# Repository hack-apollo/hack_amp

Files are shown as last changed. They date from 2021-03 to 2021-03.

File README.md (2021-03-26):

HACK LABS POWER AMP (TPA3116D2) : https://www.youtube.com/watch?v=O-adCBWkxsg&t=2s                                                                             
Author: HACK实验室                                                                                     
YouTube ID: HACK实验室, welcome to subscribe https://www.youtube.com/c/HACK实验室                                                       
HACK_PowerAmp is a free download and may be used, modified, evaluated and
distributed without charge provided the user adheres to version three of the GNU
General Public License (GPL) and does not remove the copyright notice or this
text.  The GPL V3 text is available on the gnu.org web site
作者：HACK实验室                                                                                        
B站ID：HACK实验室  欢迎订阅 https://space.bilibili.com/395145107                                                                            
微信公众号：HACK实验室，开源资料唯一发布点，定期分享开源硬件以及有价值的技术文章，欢迎关注.   

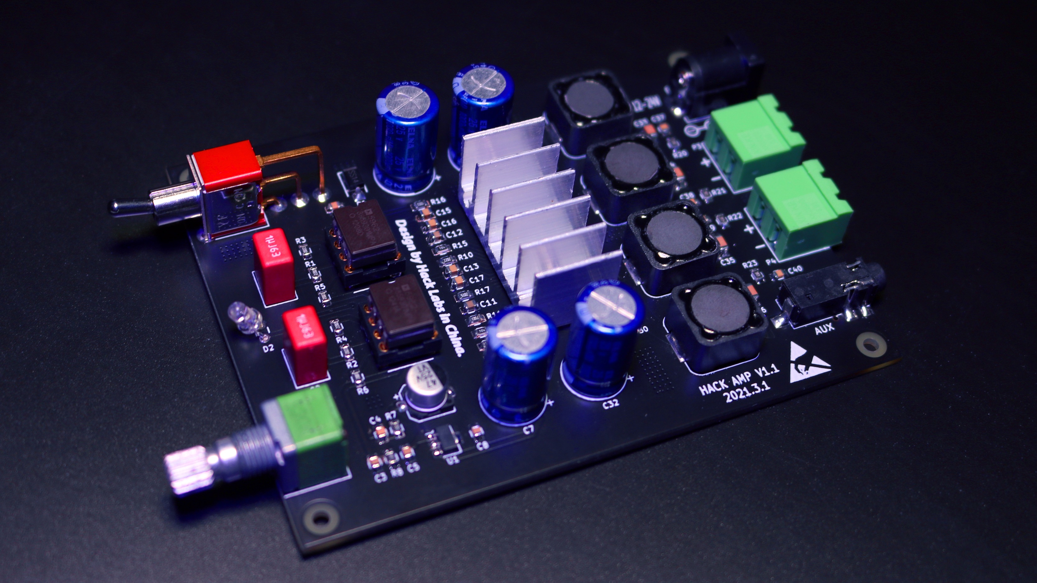
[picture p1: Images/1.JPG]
Image text


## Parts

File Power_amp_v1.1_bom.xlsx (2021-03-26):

编号 | 名称 | 值 | 封装 | 数量 | 备注
C1,C2 | WIMA MKS 02 | 1uF ±5% 63V | 脚距5mm | 2
C3,C4,C5,C8,C9,C29,C30,C51,C52 | X7R | 0.1uF ±10% 50V | 0805_C | 9
C6,C7,C31,C32 | 伊娜电容 | 220uF 35V（或1000uF/25V） | 10*16mm | 4 | 需注意电源电压要小于耐压值，且需留有余量
C10 | 贴片铝电解电容 | 47UF 25V | 6.3*5.4mm | 1
C11,C12,C13,C15,C16,C17 | X7R | 1uF ±10% 25V | 0805_C | 6
C27,C28 | X7R | 1nF(1000pF) ±5% 50V | 0805_C | 2
C19,C20,C21,C22 | X5R | 220nF ±10% 35V | 0805_C | 4
C33,C34,C35,C36 | X7R | 680nF ±10% 50V | 1206_C | 4
C37,C38,C39,C40 | X7R | 10nF ±10% 100V | 0805_C | 4
R1,R2,R5,R6,R9 |  | 10KΩ | 0805_R | 5
R3,R4,R10 |  | 20KΩ | 0805_R | 3
R7,R8,R12,R13,R14,R15,R16 |  | 100KΩ | 0805_R | 7
R11 |  | 750KΩ | 0805_R | 1
R17 |  | 51KΩ | 0805_R | 1 | 大小决定开机延时时间
R20,R21,R22,R23 |  | 3.3Ω | 0805_R | 4
D1 | 肖特基二极管 | SS34 | SMA | 1
D2 | 直插LED灯 |  | 脚距2.54mm | 1
L1,L2,L3,L4 | 贴片电感 | CDRH127 10uH/5.4A | 12*12*7mm | 4
U1 | CJ78L12 | 0.1A/12V | SOT-89-3 | 1
U2,U3 | NE5532P |  | DIP-8 | 2
U4 | TPA3116D2 |  | TSSOP-32 | 1
SW1 | 钮子开关 | MTS-102C4 |  | 1
RV1 | 09型双联电位器 | B20K |  | 1
CON1 | 电源母座 | DC-005-2.5内芯 |  | 1
P2 | 3.5音频母座 | PJ-328 | 贴片 | 1
P3,P4 | 接线端子 | 2EDG5.08-2P |  | 2
如果整理有误还望见谅，可到“HACK实验室”微信公众号私信通知修改，谢谢！

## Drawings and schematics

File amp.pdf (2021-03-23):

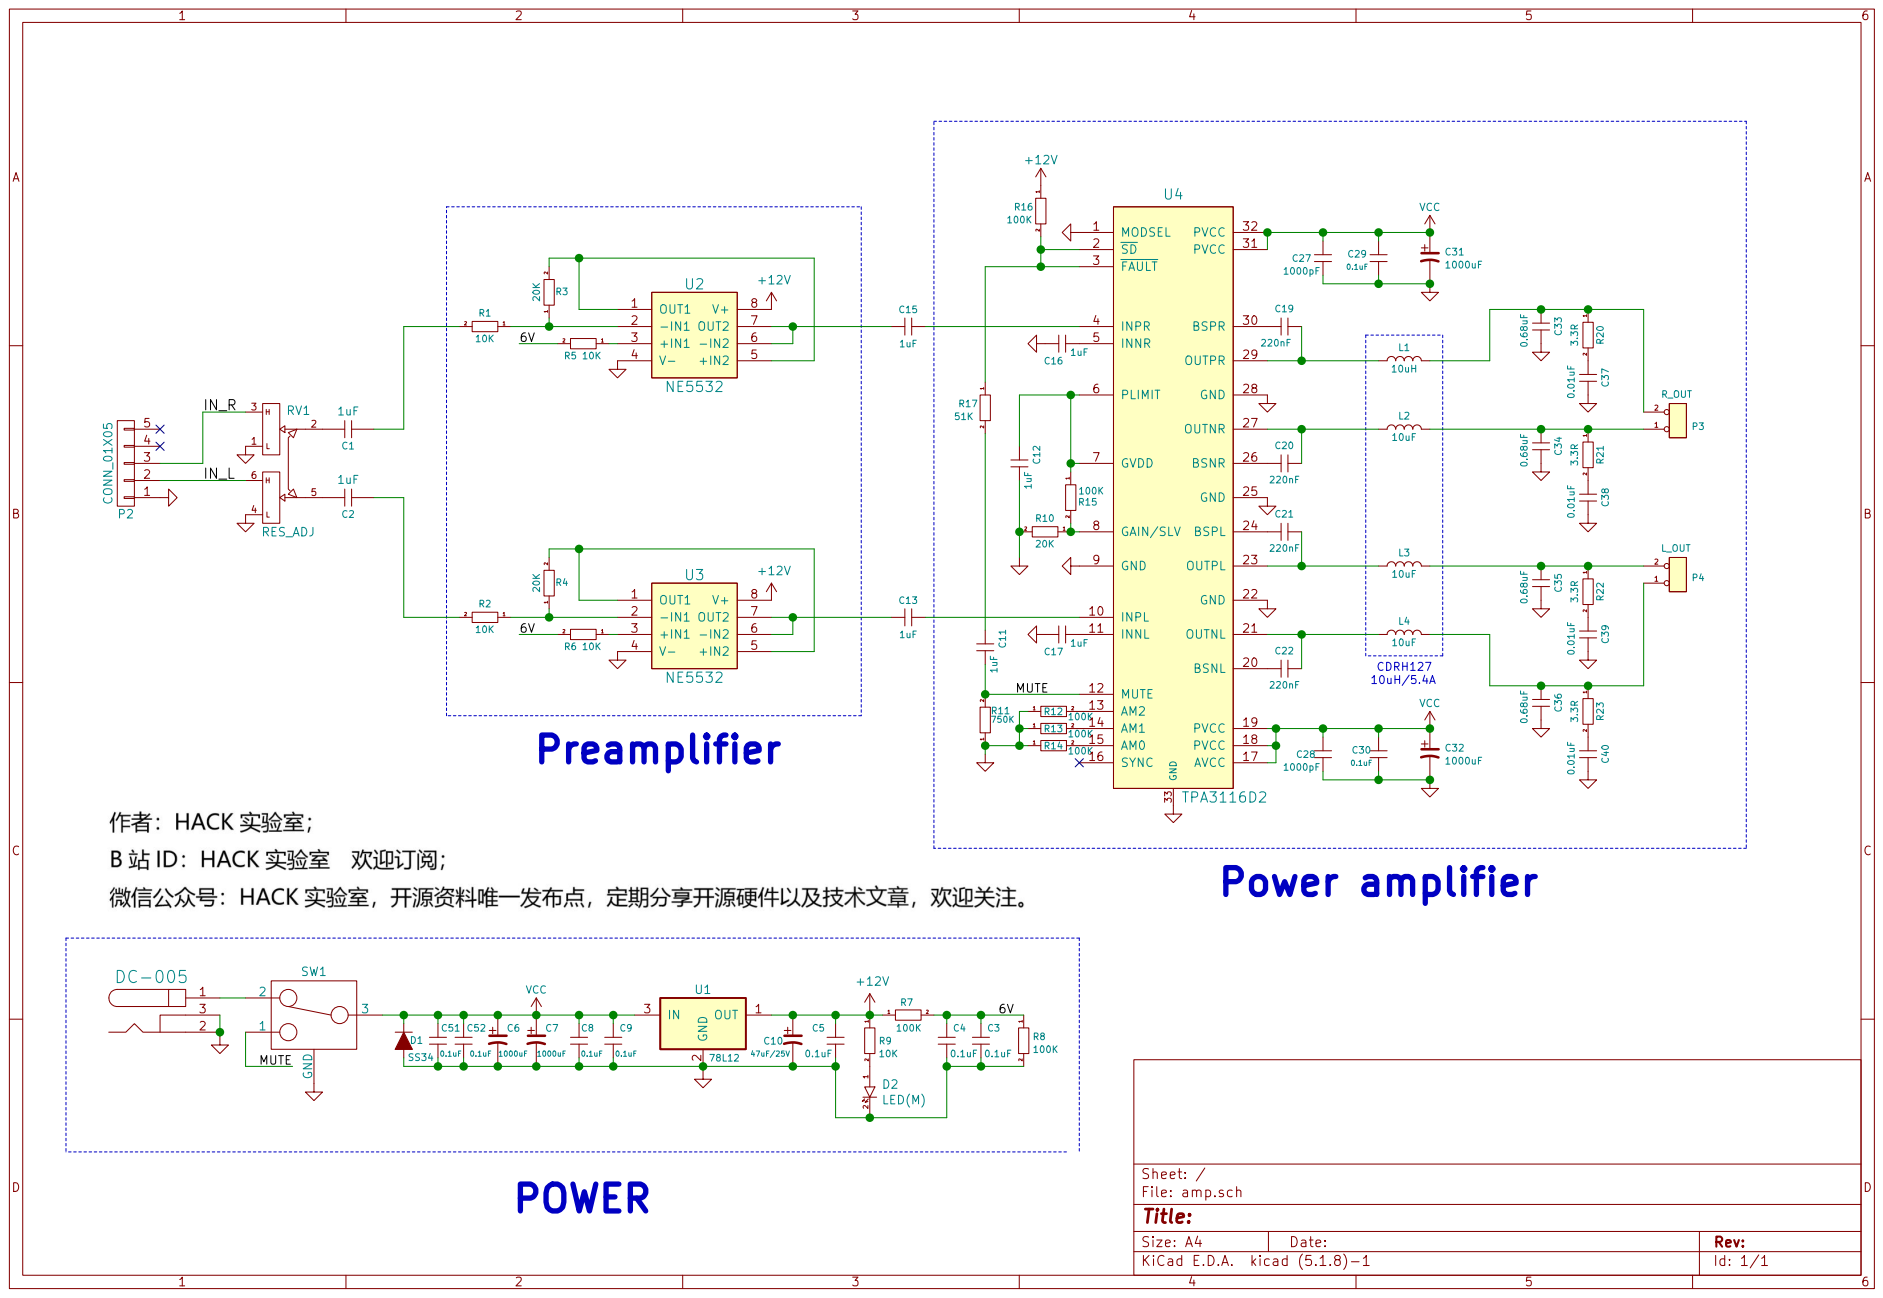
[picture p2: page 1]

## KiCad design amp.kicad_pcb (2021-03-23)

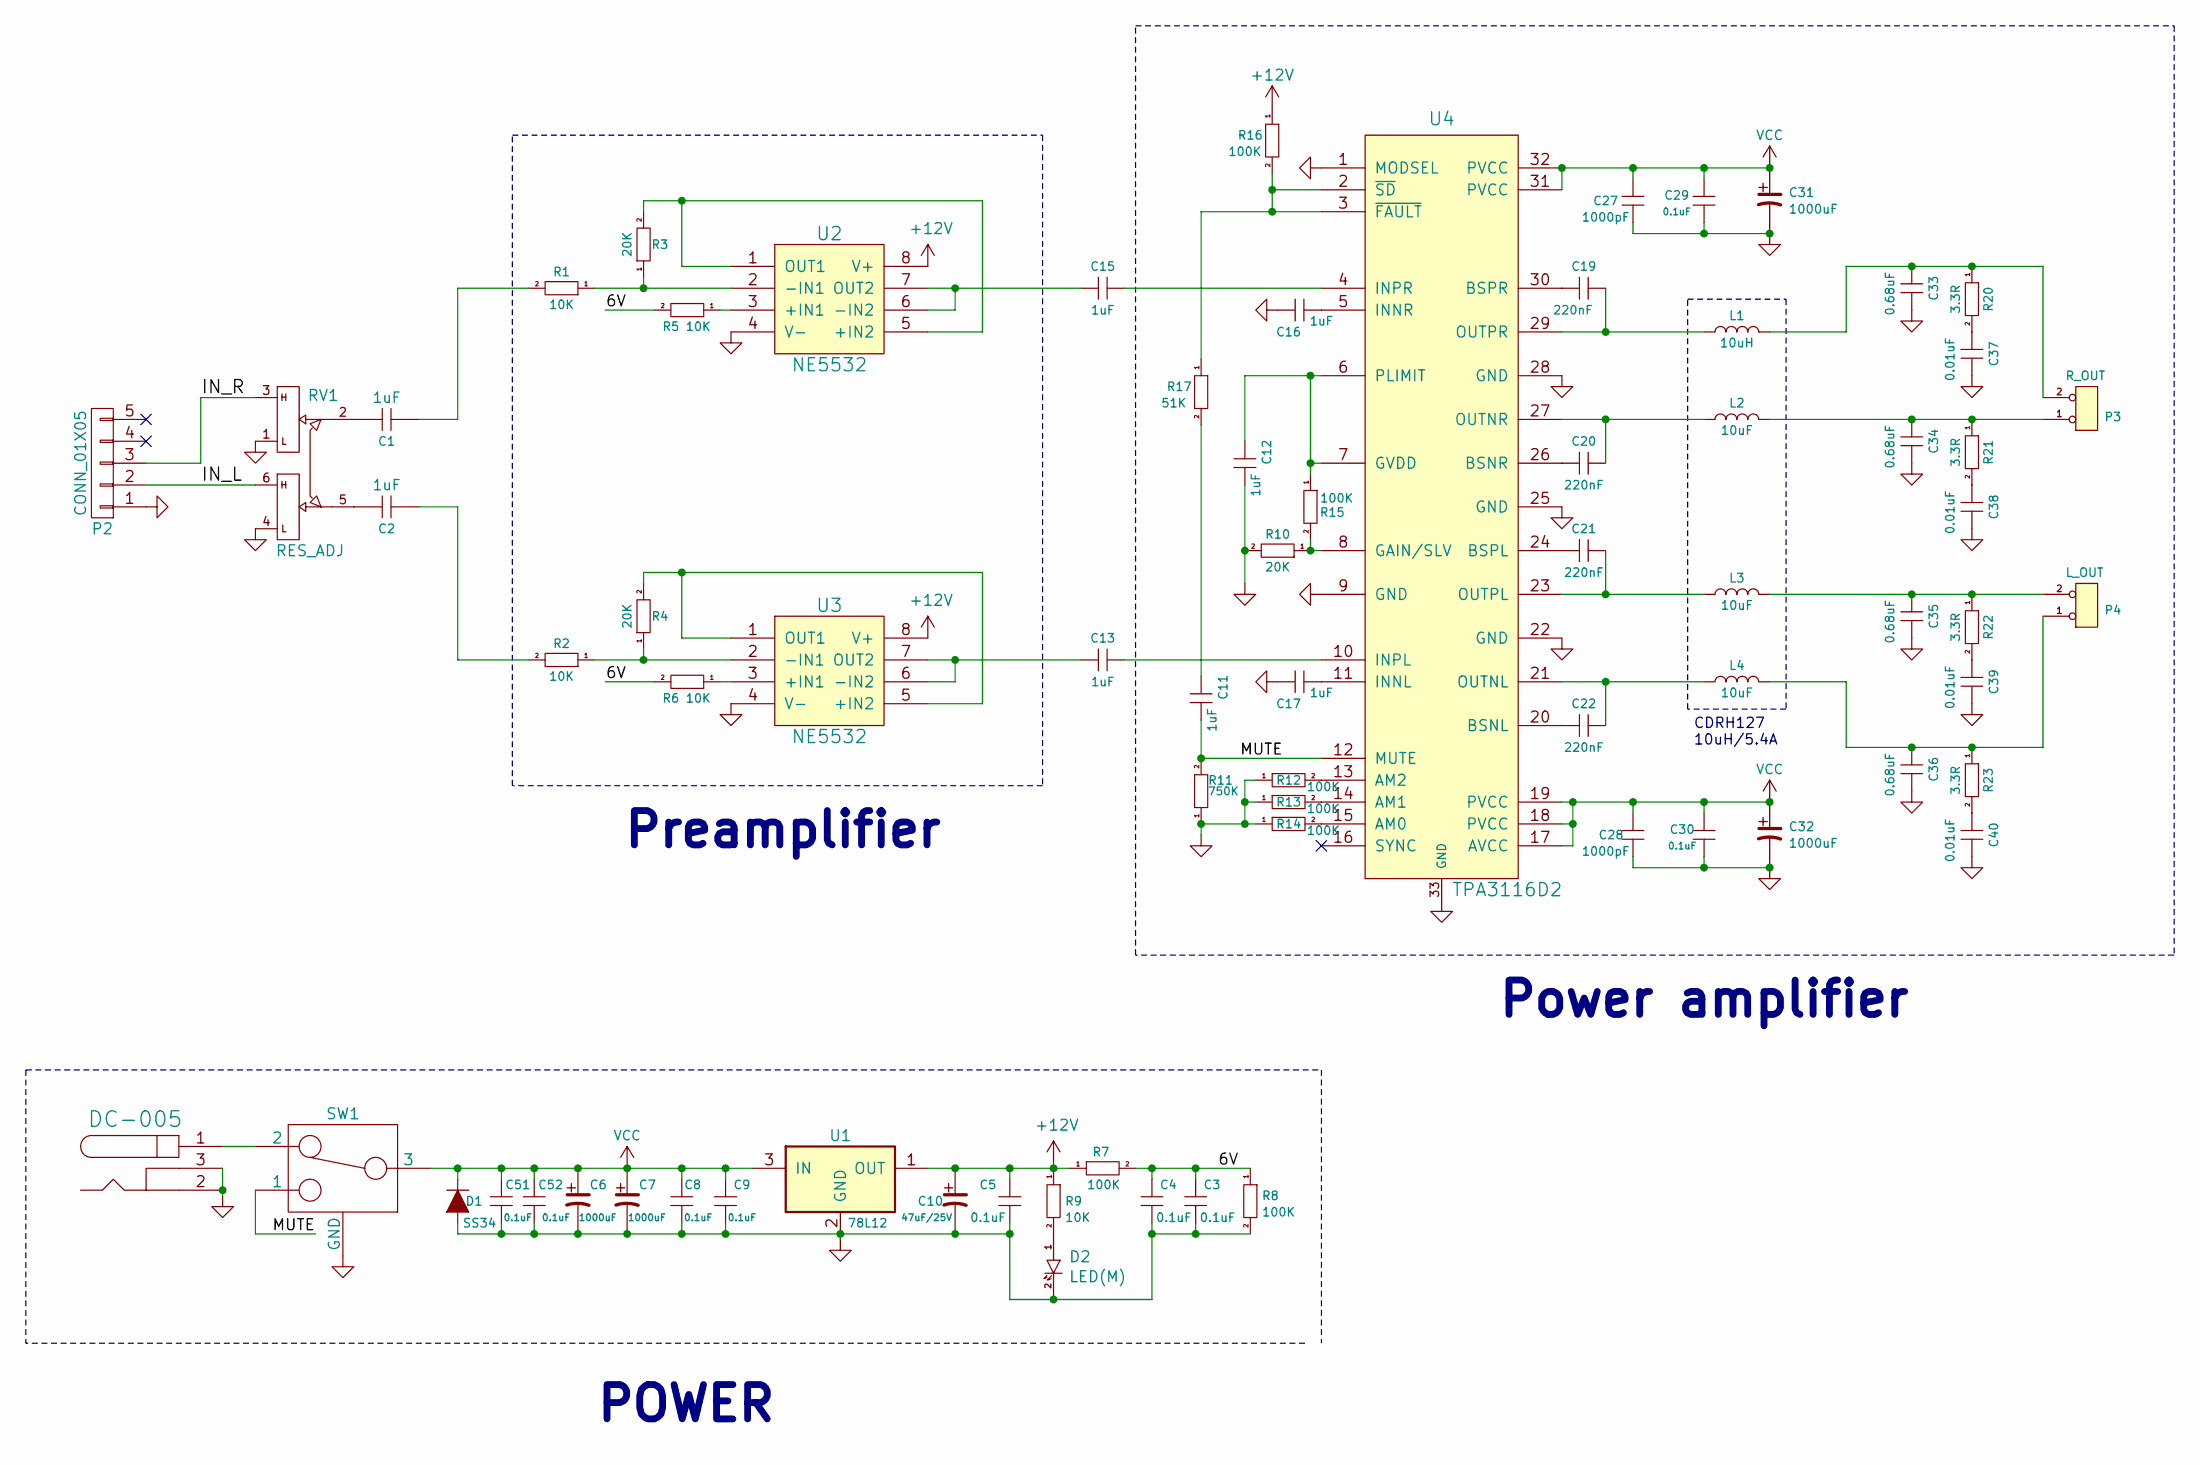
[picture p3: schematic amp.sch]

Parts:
C1, C2: 1uF; CP_Radial_D5.0mm_P2.50mm
C3, C4, C5, C8, C9, C29, C30, C51, C52: 0.1uF; 0805_C
C6, C7, C31, C32: 1000uF; CP_Radial_D10.0mm_P5.00mm
C10: 47uF/25V; CP_Radial_D10.0mm_P5.00mm
C11, C12, C13, C15, C16, C17: 1uF; 0805_C
C19, C20, C21, C22: 220nF; 0805_C
C27, C28: 1000pF; 0805_C
C33, C34, C35, C36: 0.68uF; 0805_C
C37, C38, C39, C40: 0.01uF; 0805_C
CON1: DC-005; DCDCJACK_ALIM
D1: SS34; D_SMA
D2: LED(M); LED-3MM
L1: 10uH; L_Bourns_SRR1260
L2, L3, L4: 10uF; L_Bourns_SRR1260
P2: CONN_01X05; Audio_3.5mm
P3: R_OUT; PhoenixContact_MSTBA_2,5_2-G_1x02_P5.00mm_Horizontal
P4: L_OUT; PhoenixContact_MSTBA_2,5_2-G_1x02_P5.00mm_Horizontal
R1, R2, R5, R6, R9: 10K; 0805_R
R3, R4, R10: 20K; 0805_R
R7, R8, R12, R13, R14, R15, R16: 100K; 0805_R
R11: 750K; 0805_R
R17: 51K; 0805_R
R20, R21, R22, R23: 3.3R; 0805_R
RV1: RES_ADJ; ADJ_RES
SW1: SWITCH_INV; SWITCH_Toggle
U1: 78L12; SOT-89-3
U2, U3: NE5532; DIP-8_NEW
U4: TPA3116D2; HTSSOP-32-1EP

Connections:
+9V: C5.1, C10.1, R7.1, R9.1, R16.1, U1.1 (OUT), U2.8 (V+), U3.8 (V+)
/4.5V: C3.1, C4.1, R5.2, R6.2, R7.2, R8.1
/IN_L: P2.2, RV1.6
/IN_R: P2.3, RV1.3
/MUTE: C11.2, R11.2, SW1.1, U4.12 (MUTE)
GND: C3.2, C4.2, C5.2, C6.2, C7.2, C8.2, C9.2, C10.2, C12.2, C16.1, C17.1, C27.2, C28.2, C29.2, C30.2, C31.2, C32.2, C33.1, C34.1, C35.1, C36.1, C37.1, C38.1, C39.1, C40.1, C51.2, C52.2, CON1.2, CON1.3, D1.1 (A), D2.2 (K), P2.1, R8.2, R10.2, R11.1, R12.1, R13.1, R14.1, RV1.1, RV1.4, SW1.0 (GND), U1.2 (GND), U2.4 (V-), U3.4 (V-), U4.1 (MODSEL), U4.9 (GND), U4.22 (GND), U4.25 (GND), U4.28 (GND), U4.33 (GND)
unnamed: C1.1, RV1.2
unnamed: C1.2, R1.2
unnamed: C2.1, RV1.5
unnamed: C2.2, R2.2
unnamed: C11.1, R17.2
unnamed: C12.1, R15.1, U4.6 (PLIMIT), U4.7 (GVDD)
unnamed: C13.1, U3.6 (-IN2), U3.7 (OUT2)
unnamed: C13.2, U4.10 (INPL)
unnamed: C15.1, U2.6 (-IN2), U2.7 (OUT2)
unnamed: C15.2, U4.4 (INPR)
unnamed: C16.2, U4.5 (INNR)
unnamed: C17.2, U4.11 (INNL)
unnamed: C19.1, L1.1, U4.29 (OUTPR)
unnamed: C19.2, U4.30 (BSPR)
unnamed: C20.1, L2.1, U4.27 (OUTNR)
unnamed: C20.2, U4.26 (BSNR)
unnamed: C21.1, L3.1, U4.23 (OUTPL)
unnamed: C21.2, U4.24 (BSPL)
unnamed: C22.1, L4.1, U4.21 (OUTNL)
unnamed: C22.2, U4.20 (BSNL)
unnamed: C33.2, L1.2, P3.2 (PM), R20.1
unnamed: C34.2, L2.2, P3.1, R21.1
unnamed: C35.2, L3.2, P4.2 (PM), R22.1
unnamed: C36.2, L4.2, P4.1, R23.1
unnamed: C37.2, R20.2
unnamed: C38.2, R21.2
unnamed: C39.2, R22.2
unnamed: C40.2, R23.2
unnamed: CON1.1, SW1.2
unnamed: D2.1 (A), R9.2
unnamed: R1.1, R3.1, U2.2 (-IN1)
unnamed: R2.1, R4.1, U3.2 (-IN1)
unnamed: R3.2, U2.1 (OUT1), U2.5 (+IN2)
unnamed: R4.2, U3.1 (OUT1), U3.5 (+IN2)
unnamed: R5.1, U2.3 (+IN1)
unnamed: R6.1, U3.3 (+IN1)
unnamed: R10.1, R15.2, U4.8 (GAIN/SLV)
unnamed: R12.2, U4.13 (AM2)
unnamed: R13.2, U4.14 (AM1)
unnamed: R14.2, U4.15 (AM0)
unnamed: R16.2, R17.1, U4.2 (~SD), U4.3 (~FAULT)
VCC: C6.1, C7.1, C8.1, C9.1, C27.1, C28.1, C29.1, C30.1, C31.1, C32.1, C51.1, C52.1, D1.2 (K), SW1.3, U1.3 (IN), U4.17 (AVCC), U4.18 (PVCC), U4.19 (PVCC), U4.31 (PVCC), U4.32 (PVCC)

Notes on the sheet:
CDRH127 10uH/5.4A
POWER
Preamplifier
Power amplifier

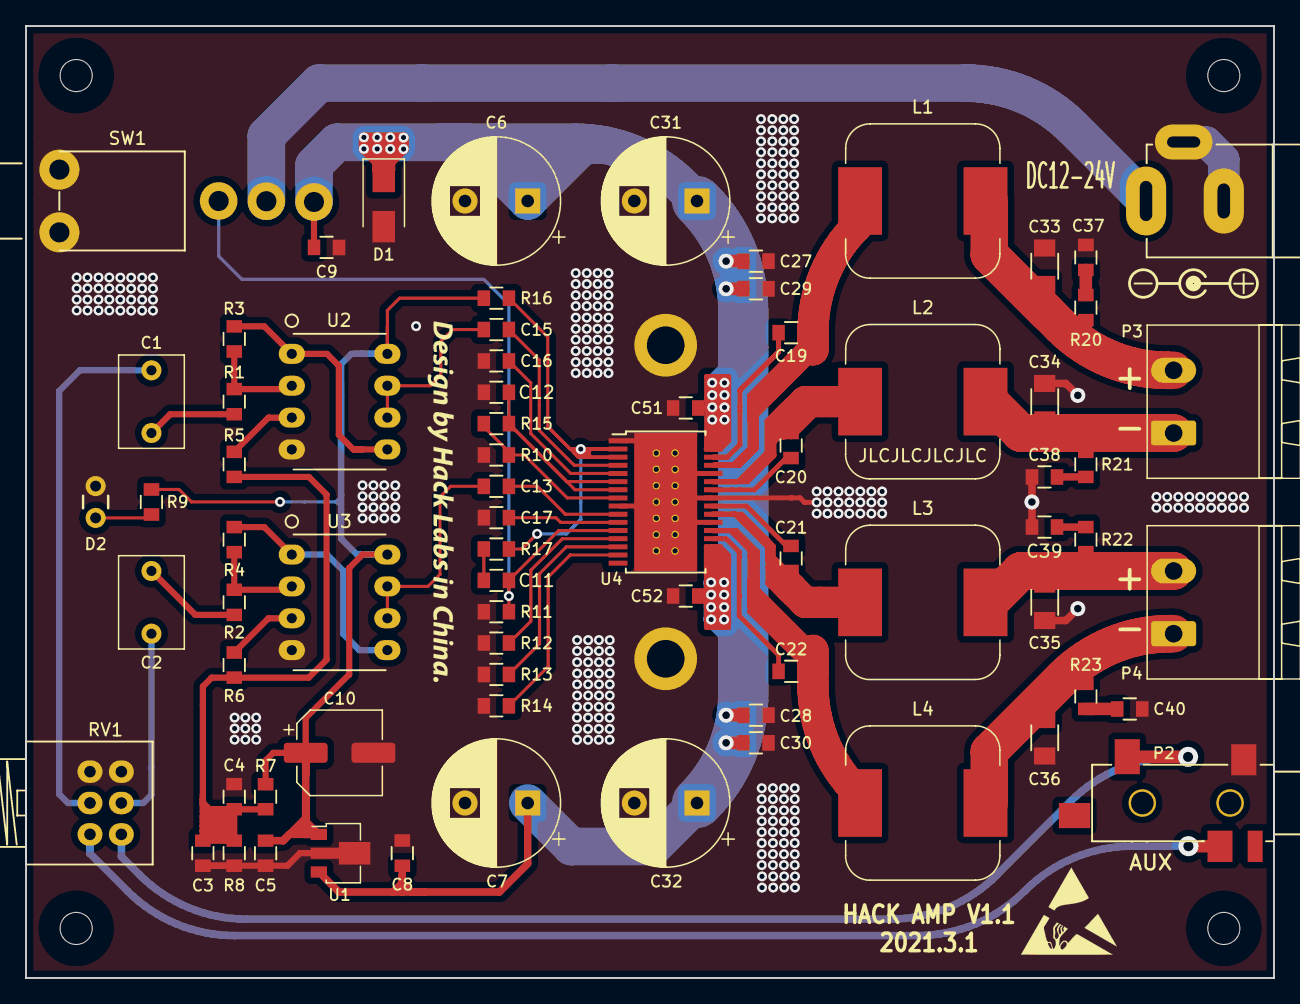
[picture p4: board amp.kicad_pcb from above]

Board: 2 copper layers, 99.5 x 75.9 mm, 73 parts (0 on the bottom side), 48 nets.

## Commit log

2021-03-23 first add
    [HiFi功放V1.1元器件清单.xlsx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]
2021-03-23 repare bom
    [Power_amp_v1.1_bom.xlsx]
2021-03-26 repare bom ——R11
    [Power_amp_v1.1_bom.xlsx]
